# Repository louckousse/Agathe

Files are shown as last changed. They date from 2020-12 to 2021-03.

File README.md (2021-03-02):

# Agathe
Another Alice-clone

Following a 65% approach with close arrow-cluster and support for rotary encoders

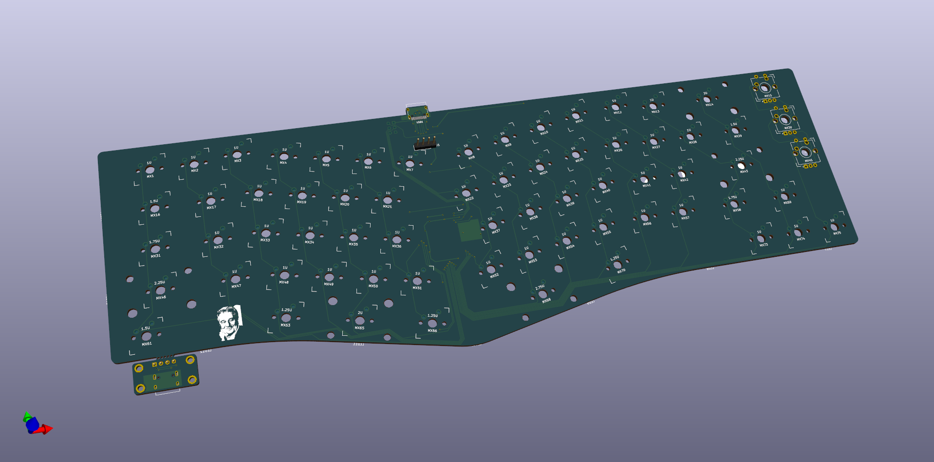
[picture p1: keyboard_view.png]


All the pcb files are created in Kicad, you can find everything in the root folder.

## Development

clone this repos with submodules
```
git clone --recurse-submodule https://github.com/louckousse/Agathe.git
```

## Building
When building this keyboard if you want to use the one rotary encoders you'll have to solder the jumper between the middle pad to the pad 1. If you want to use multiple, solder the other way around and check [this pr](https://github.com/qmk/qmk_firmware/pull/7209).
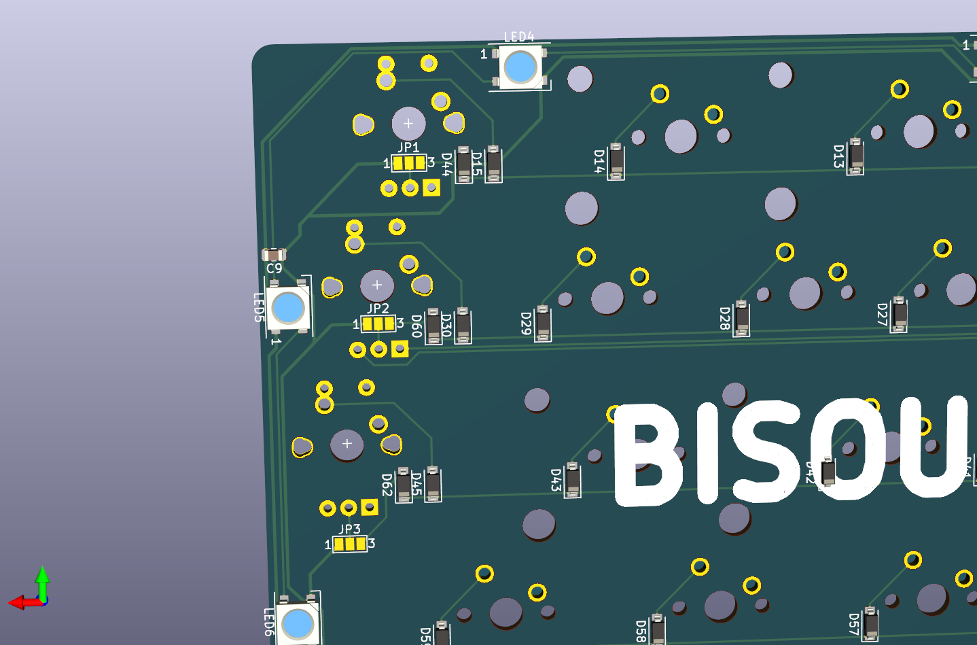
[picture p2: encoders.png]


## Keymap
You can find the keymap under my [QMK fork](https://github.com/louckousse/keymaps/tree/main/agathe).

# License
This work is licensed under a [Attribution-NonCommercial-ShareAlike 4.0 International (CC BY-NC-SA 4.0)](https://creativecommons.org/licenses/by-nc-sa/4.0/).

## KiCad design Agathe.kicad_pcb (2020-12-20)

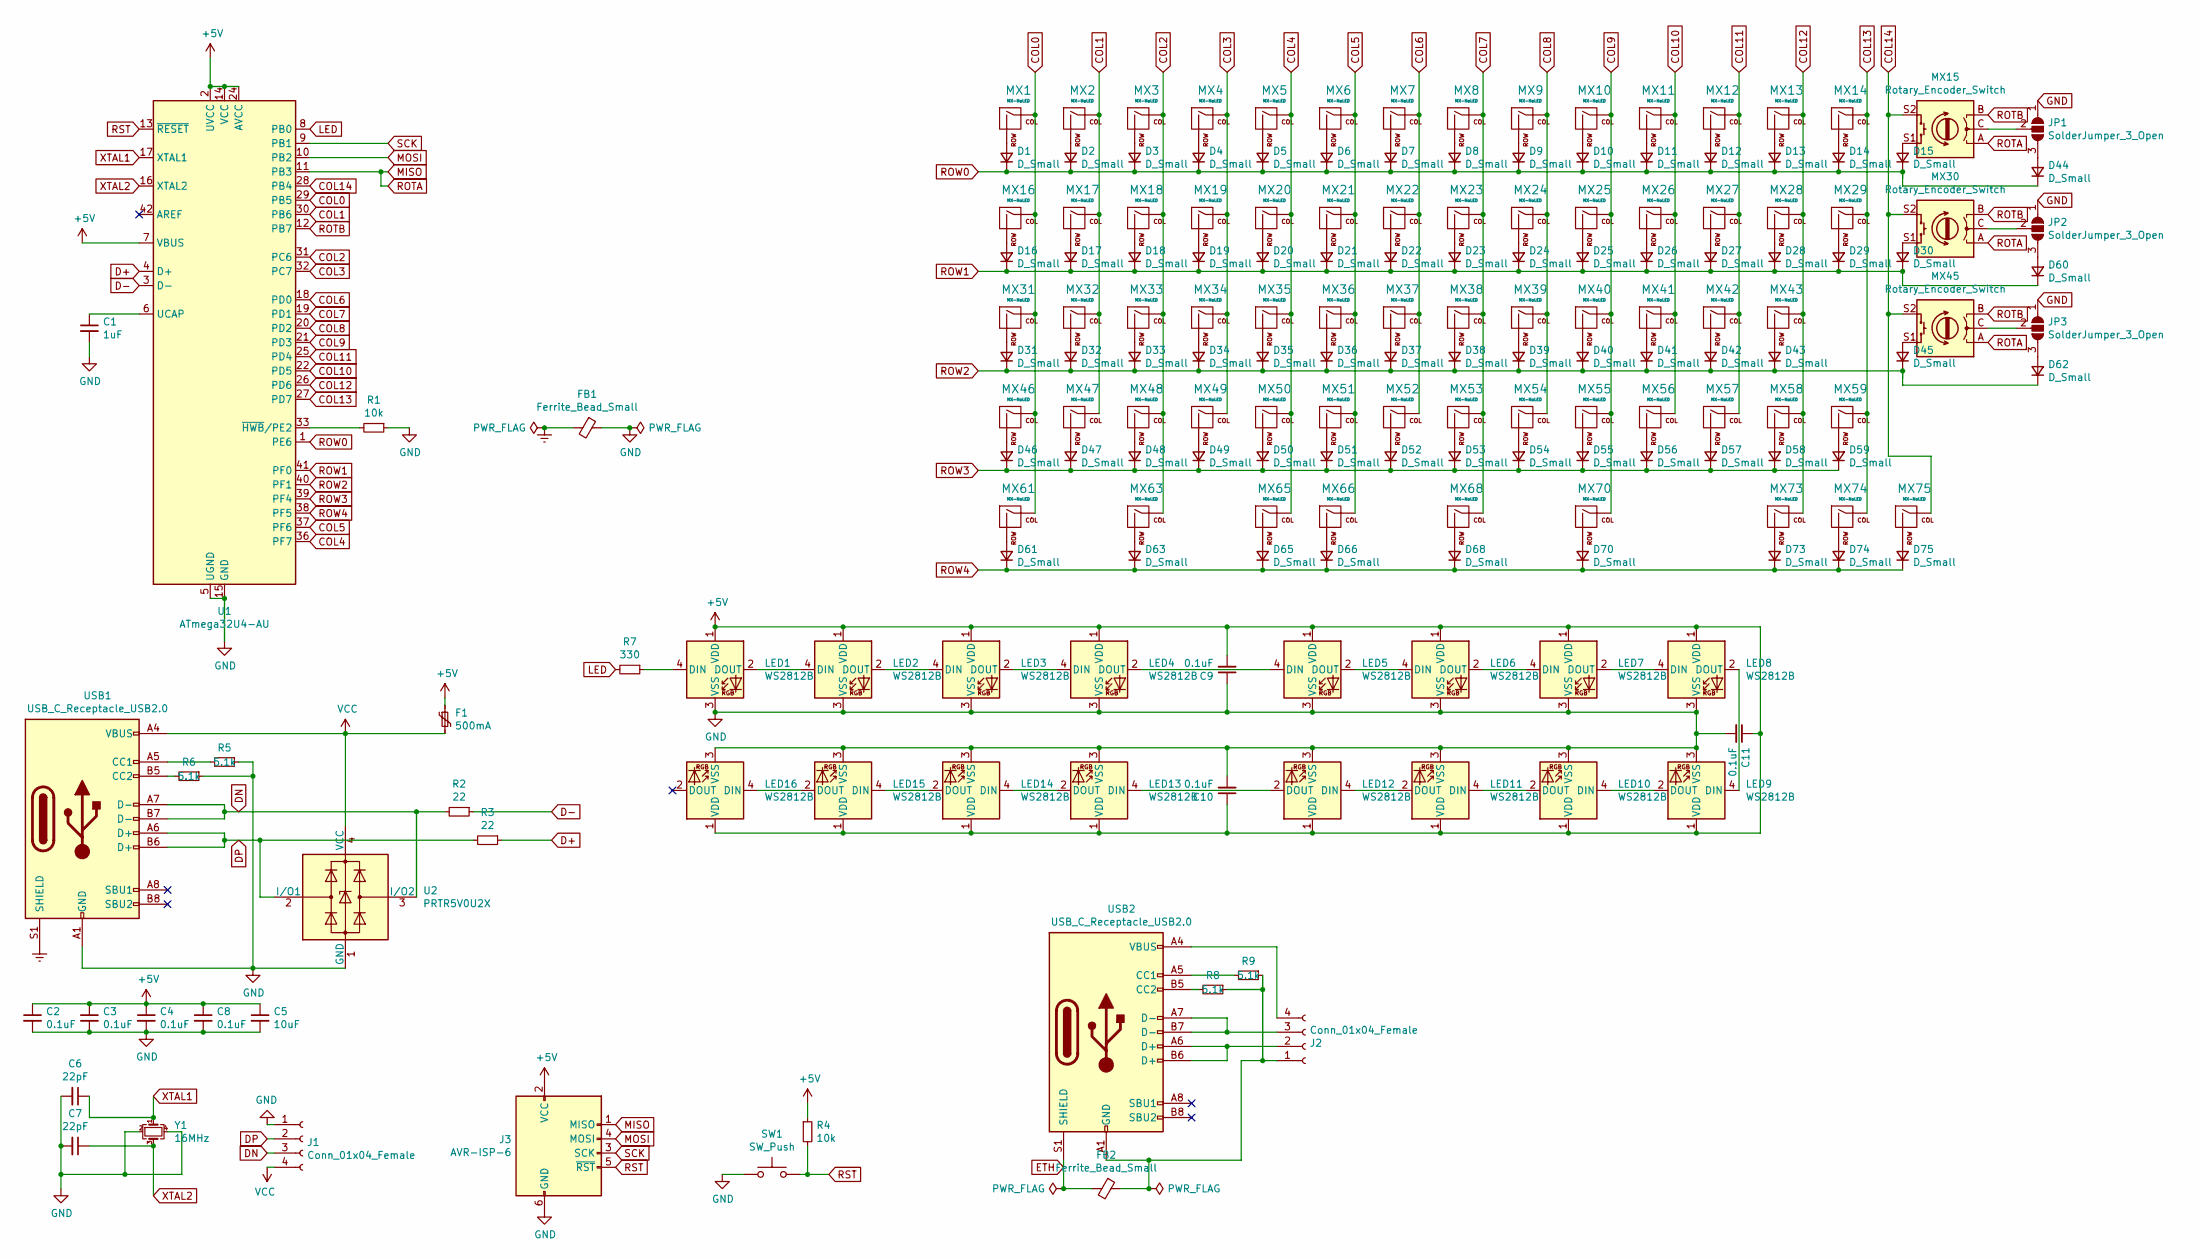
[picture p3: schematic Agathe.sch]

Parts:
C1: 1uF; C_0805_2012Metric
C2, C3, C4, C8, C9, C10, C11: 0.1uF; C_0805_2012Metric
C5: 10uF; C_0805_2012Metric
C6, C7: 22pF; C_0805_2012Metric
D1, D2, D3, D4, D5, D6, D7, D8, D9, D10, D11, D12, D13, D14, D15, D16, D17, D18, D19, D20, D21, D22, D23, D24, D25, D26, D27, D28, D29, D30, D31, D32, D33, D34, D35, D36, D37, D38, D39, D40, D41, D42, D43, D44, D45, D46, D47, D48, D49, D50, D51, D52, D53, D54, D55, D56, D57, D58, D59, D60, D61, D62, D63, D65, D66, D68, D70, D73, D74, D75: D_Small; D_SOD-123
F1: 500mA; Fuse_1206_3216Metric
FB1, FB2: Ferrite_Bead_Small; L_0805_2012Metric_Pad1.15x1.40mm_HandSolder
J1, J2: Conn_01x04_Female; PinHeader_1x04_P2.54mm_Vertical
J3: AVR-ISP-6; Reset_Pretty-Mask
JP1, JP2, JP3: SolderJumper_3_Open; SolderJumper-3_P1.3mm_Open_Pad1.0x1.5mm_NumberLabels
LED1, LED2, LED3, LED4, LED5, LED6, LED7, LED8, LED9, LED10, LED11, LED12, LED13, LED14, LED15, LED16: WS2812B; LED_WS2812B_PLCC4_5.0x5.0mm_P3.2mm
MX1, MX2, MX3, MX4, MX5, MX6, MX7, MX8, MX9, MX10, MX11, MX12, MX13, MX17, MX18, MX19, MX20, MX21, MX22, MX23, MX24, MX25, MX26, MX27, MX28, MX32, MX33, MX34, MX35, MX36, MX37, MX38, MX39, MX40, MX41, MX42, MX47, MX48, MX49, MX50, MX51, MX52, MX53, MX54, MX55, MX56, MX57, MX59, MX73, MX74, MX75: MX-NoLED; mx_1u
MX14: MX-NoLED; mx_2u
MX15, MX30, MX45: Rotary_Encoder_Switch; rotary_x_MX
MX16, MX29, MX61: MX-NoLED; mx_15u
MX31, MX58: MX-NoLED; mx_175u
MX43, MX46: MX-NoLED; mx_225u
MX63, MX66, MX70: MX-NoLED; mx_125u
MX65: MX-NoLED; mx_2ureverse
MX68: MX-NoLED; mx_275u_reverse
R1, R4: 10k; R_0805_2012Metric
R2, R3: 22; R_0805_2012Metric
R5, R6, R8, R9: 5.1k; R_0805_2012Metric
R7: 330; R_0805_2012Metric
SW1: SW_Push; SKQG-1155865
U1: ATmega32U4-AU; QFN-44-1EP_7x7mm_P0.5mm_EP5.2x5.2mm
U2: PRTR5V0U2X; SOT143B
USB1, USB2: USB_C_Receptacle_USB2.0; USB_C_Receptacle_HRO_TYPE-C-31-M-12
Y1: 16MHz; Crystal_SMD_3225-4Pin_3.2x2.5mm

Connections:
+5V: C2.1, C3.1, C4.1, C5.1, C8.1, C9.2, C10.1, C11.1, F1.1, J3.2 (VCC), LED1.1 (VDD), LED2.1 (VDD), LED3.1 (VDD), LED4.1 (VDD), LED5.1 (VDD), LED6.1 (VDD), LED7.1 (VDD), LED8.1 (VDD), LED9.1 (VDD), LED10.1 (VDD), LED11.1 (VDD), LED12.1 (VDD), LED13.1 (VDD), LED14.1 (VDD), LED15.1 (VDD), LED16.1 (VDD), R4.1, U1.2 (UVCC), U1.7 (VBUS), U1.14 (VCC), U1.24 (AVCC), U1.34 (VCC), U1.44 (AVCC)
COL0: MX1.1 (COL), MX16.1 (COL), MX31.1 (COL), MX46.1 (COL), MX61.1 (COL), U1.29 (PB5)
COL1: MX2.1 (COL), MX17.1 (COL), MX32.1 (COL), MX47.1 (COL), U1.30 (PB6)
COL2: MX3.1 (COL), MX18.1 (COL), MX33.1 (COL), MX48.1 (COL), MX63.1 (COL), U1.31 (PC6)
COL3: MX4.1 (COL), MX19.1 (COL), MX34.1 (COL), MX49.1 (COL), U1.32 (PC7)
COL4: MX5.1 (COL), MX20.1 (COL), MX35.1 (COL), MX50.1 (COL), MX65.1 (COL), U1.36 (PF7)
COL5: MX6.1 (COL), MX21.1 (COL), MX36.1 (COL), MX51.1 (COL), MX66.1 (COL), U1.37 (PF6)
COL6: MX7.1 (COL), MX22.1 (COL), MX37.1 (COL), MX52.1 (COL), U1.18 (PD0)
COL7: MX8.1 (COL), MX23.1 (COL), MX38.1 (COL), MX53.1 (COL), MX68.1 (COL), U1.19 (PD1)
COL8: MX9.1 (COL), MX24.1 (COL), MX39.1 (COL), MX54.1 (COL), U1.20 (PD2)
COL9: MX10.1 (COL), MX25.1 (COL), MX40.1 (COL), MX55.1 (COL), MX70.1 (COL), U1.21 (PD3)
COL10: MX11.1 (COL), MX26.1 (COL), MX41.1 (COL), MX56.1 (COL), U1.22 (PD5)
COL11: MX12.1 (COL), MX27.1 (COL), MX42.1 (COL), MX57.1 (COL), U1.25 (PD4)
COL12: MX13.1 (COL), MX28.1 (COL), MX43.1 (COL), MX58.1 (COL), MX73.1 (COL), U1.26 (PD6)
COL13: MX14.1 (COL), MX29.1 (COL), MX59.1 (COL), MX74.1 (COL), U1.27 (PD7)
COL14: MX15.S2, MX30.S2, MX45.S2, MX75.1 (COL), U1.28 (PB4)
D+: R3.1, U1.4 (D+)
D-: R2.1, U1.3 (D-)
DN: J1.3, R2.2, U2.3 (I/O2), USB1.A7 (D-), USB1.B7 (D-)
DP: J1.2, R3.2, U2.2 (I/O1), USB1.A6 (D+), USB1.B6 (D+)
ETH: FB2.2, USB2.S1 (SHIELD)
Earth: FB1.2, USB1.S1 (SHIELD)
GND: C1.2, C2.2, C3.2, C4.2, C5.2, C6.2, C7.2, C8.2, C9.1, C10.2, C11.2, FB1.1, J1.1, J3.6 (GND), JP1.1 (A), JP2.1 (A), JP3.1 (A), LED1.3 (VSS), LED2.3 (VSS), LED3.3 (VSS), LED4.3 (VSS), LED5.3 (VSS), LED6.3 (VSS), LED7.3 (VSS), LED8.3 (VSS), LED9.3 (VSS), LED10.3 (VSS), LED11.3 (VSS), LED12.3 (VSS), LED13.3 (VSS), LED14.3 (VSS), LED15.3 (VSS), LED16.3 (VSS), R1.1, R5.1, R6.1, SW1.1, U1.5 (UGND), U1.15 (GND), U1.23 (GND), U1.35 (GND), U1.43 (GND), U1.45, U2.1 (GND), USB1.A1 (GND), USB1.A12 (GND), USB1.B1 (GND), USB1.B12 (GND), Y1.2, Y1.4
LED: R7.2, U1.8 (PB0)
MISO: J3.1 (MISO), MX15.A, MX30.A, MX45.A, U1.11 (PB3)
MOSI: J3.4 (MOSI), U1.10 (PB2)
unnamed: C1.1, U1.6 (UCAP)
unnamed: D1.2 (A), MX1.2 (ROW)
unnamed: D2.2 (A), MX2.2 (ROW)
unnamed: D3.2 (A), MX3.2 (ROW)
unnamed: D4.2 (A), MX4.2 (ROW)
unnamed: D5.2 (A), MX5.2 (ROW)
unnamed: D6.2 (A), MX6.2 (ROW)
unnamed: D7.2 (A), MX7.2 (ROW)
unnamed: D8.2 (A), MX8.2 (ROW)
unnamed: D9.2 (A), MX9.2 (ROW)
unnamed: D10.2 (A), MX10.2 (ROW)
unnamed: D11.2 (A), MX11.2 (ROW)
unnamed: D12.2 (A), MX12.2 (ROW)
unnamed: D13.2 (A), MX13.2 (ROW)
unnamed: D14.2 (A), MX14.2 (ROW)
unnamed: D15.2 (A), MX15.S1
unnamed: D16.2 (A), MX16.2 (ROW)
unnamed: D17.2 (A), MX17.2 (ROW)
unnamed: D18.2 (A), MX18.2 (ROW)
unnamed: D19.2 (A), MX19.2 (ROW)
unnamed: D20.2 (A), MX20.2 (ROW)
unnamed: D21.2 (A), MX21.2 (ROW)
unnamed: D22.2 (A), MX22.2 (ROW)
unnamed: D23.2 (A), MX23.2 (ROW)
unnamed: D24.2 (A), MX24.2 (ROW)
unnamed: D25.2 (A), MX25.2 (ROW)
unnamed: D26.2 (A), MX26.2 (ROW)
unnamed: D27.2 (A), MX27.2 (ROW)
unnamed: D28.2 (A), MX28.2 (ROW)
unnamed: D29.2 (A), MX29.2 (ROW)
unnamed: D30.2 (A), MX30.S1
unnamed: D31.2 (A), MX31.2 (ROW)
unnamed: D32.2 (A), MX32.2 (ROW)
unnamed: D33.2 (A), MX33.2 (ROW)
unnamed: D34.2 (A), MX34.2 (ROW)
unnamed: D35.2 (A), MX35.2 (ROW)
unnamed: D36.2 (A), MX36.2 (ROW)
unnamed: D37.2 (A), MX37.2 (ROW)
unnamed: D38.2 (A), MX38.2 (ROW)
unnamed: D39.2 (A), MX39.2 (ROW)
unnamed: D40.2 (A), MX40.2 (ROW)
unnamed: D41.2 (A), MX41.2 (ROW)
unnamed: D42.2 (A), MX42.2 (ROW)
unnamed: D43.2 (A), MX43.2 (ROW)
unnamed: D44.2 (A), JP1.3 (B)
unnamed: D45.2 (A), MX45.S1
unnamed: D46.2 (A), MX46.2 (ROW)
unnamed: D47.2 (A), MX47.2 (ROW)
unnamed: D48.2 (A), MX48.2 (ROW)
unnamed: D49.2 (A), MX49.2 (ROW)
unnamed: D50.2 (A), MX50.2 (ROW)
unnamed: D51.2 (A), MX51.2 (ROW)
unnamed: D52.2 (A), MX52.2 (ROW)
unnamed: D53.2 (A), MX53.2 (ROW)
unnamed: D54.2 (A), MX54.2 (ROW)
unnamed: D55.2 (A), MX55.2 (ROW)
unnamed: D56.2 (A), MX56.2 (ROW)
unnamed: D57.2 (A), MX57.2 (ROW)
unnamed: D58.2 (A), MX58.2 (ROW)
unnamed: D59.2 (A), MX59.2 (ROW)
unnamed: D60.2 (A), JP2.3 (B)
unnamed: D61.2 (A), MX61.2 (ROW)
unnamed: D62.2 (A), JP3.3 (B)
unnamed: D63.2 (A), MX63.2 (ROW)
unnamed: D65.2 (A), MX65.2 (ROW)
unnamed: D66.2 (A), MX66.2 (ROW)
unnamed: D68.2 (A), MX68.2 (ROW)
unnamed: D70.2 (A), MX70.2 (ROW)
unnamed: D73.2 (A), MX73.2 (ROW)
unnamed: D74.2 (A), MX74.2 (ROW)
unnamed: D75.2 (A), MX75.2 (ROW)
unnamed: FB2.1, J2.1, R8.1, R9.1, USB2.A1 (GND), USB2.A12 (GND), USB2.B1 (GND), USB2.B12 (GND)
unnamed: J2.2, USB2.A6 (D+), USB2.B6 (D+)
unnamed: J2.3, USB2.A7 (D-), USB2.B7 (D-)
unnamed: J2.4, USB2.A4 (VBUS), USB2.A9 (VBUS), USB2.B4 (VBUS), USB2.B9 (VBUS)
unnamed: JP1.2 (C), MX15.C
unnamed: JP2.2 (C), MX30.C
unnamed: JP3.2 (C), MX45.C
unnamed: LED1.2 (DOUT), LED2.4 (DIN)
unnamed: LED1.4 (DIN), R7.1
unnamed: LED2.2 (DOUT), LED3.4 (DIN)
unnamed: LED3.2 (DOUT), LED4.4 (DIN)
unnamed: LED4.2 (DOUT), LED5.4 (DIN)
unnamed: LED5.2 (DOUT), LED6.4 (DIN)
unnamed: LED6.2 (DOUT), LED7.4 (DIN)
unnamed: LED7.2 (DOUT), LED8.4 (DIN)
unnamed: LED8.2 (DOUT), LED9.4 (DIN)
unnamed: LED10.2 (DOUT), LED11.4 (DIN)
unnamed: LED9.2 (DOUT), LED10.4 (DIN)
unnamed: LED11.2 (DOUT), LED12.4 (DIN)
unnamed: LED12.2 (DOUT), LED13.4 (DIN)
unnamed: LED13.2 (DOUT), LED14.4 (DIN)
unnamed: LED14.2 (DOUT), LED15.4 (DIN)
unnamed: LED15.2 (DOUT), LED16.4 (DIN)
unnamed: R1.2, U1.33 (~HWB~/PE2)
unnamed: R5.2, USB1.A5 (CC1)
unnamed: R6.2, USB1.B5 (CC2)
unnamed: R8.2, USB2.B5 (CC2)
unnamed: R9.2, USB2.A5 (CC1)
ROTB: MX15.B, MX30.B, MX45.B, U1.12 (PB7)
ROW0: D1.1 (K), D2.1 (K), D3.1 (K), D4.1 (K), D5.1 (K), D6.1 (K), D7.1 (K), D8.1 (K), D9.1 (K), D10.1 (K), D11.1 (K), D12.1 (K), D13.1 (K), D14.1 (K), D15.1 (K), D44.1 (K), U1.1 (PE6)
ROW1: D16.1 (K), D17.1 (K), D18.1 (K), D19.1 (K), D20.1 (K), D21.1 (K), D22.1 (K), D23.1 (K), D24.1 (K), D25.1 (K), D26.1 (K), D27.1 (K), D28.1 (K), D29.1 (K), D30.1 (K), D60.1 (K), U1.41 (PF0)
ROW2: D31.1 (K), D32.1 (K), D33.1 (K), D34.1 (K), D35.1 (K), D36.1 (K), D37.1 (K), D38.1 (K), D39.1 (K), D40.1 (K), D41.1 (K), D42.1 (K), D43.1 (K), D45.1 (K), D62.1 (K), U1.40 (PF1)
ROW3: D46.1 (K), D47.1 (K), D48.1 (K), D49.1 (K), D50.1 (K), D51.1 (K), D52.1 (K), D53.1 (K), D54.1 (K), D55.1 (K), D56.1 (K), D57.1 (K), D58.1 (K), D59.1 (K), U1.39 (PF4)
ROW4: D61.1 (K), D63.1 (K), D65.1 (K), D66.1 (K), D68.1 (K), D70.1 (K), D73.1 (K), D74.1 (K), D75.1 (K), U1.38 (PF5)
RST: J3.5 (~RST), R4.2, SW1.2, U1.13 (~RESET)
SCK: J3.3 (SCK), U1.9 (PB1)
VCC: F1.2, J1.4, U2.4 (VCC), USB1.A4 (VBUS), USB1.A9 (VBUS), USB1.B4 (VBUS), USB1.B9 (VBUS)
XTAL1: C6.1, U1.17 (XTAL1), Y1.1
XTAL2: C7.1, U1.16 (XTAL2), Y1.3

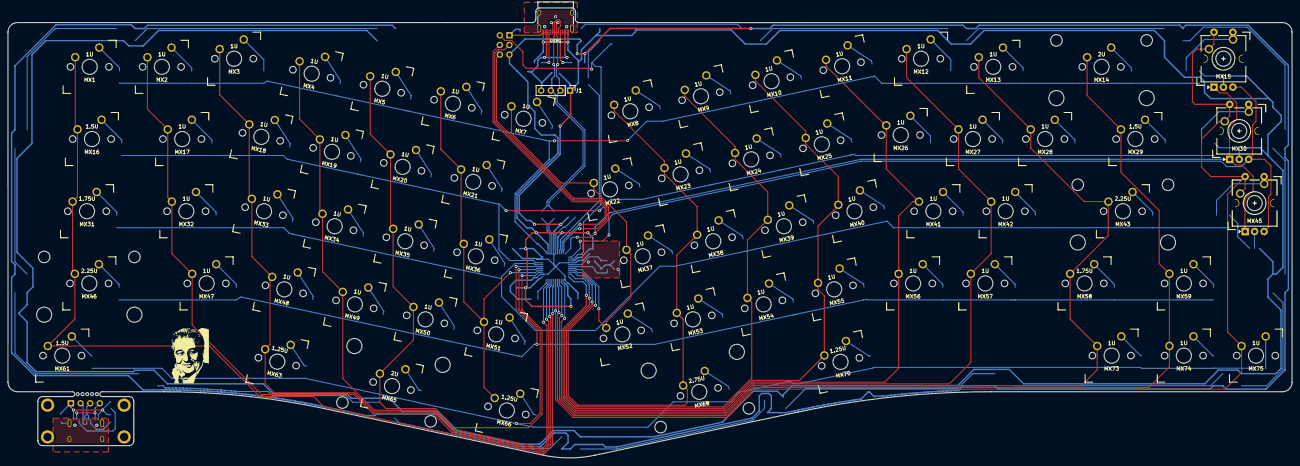
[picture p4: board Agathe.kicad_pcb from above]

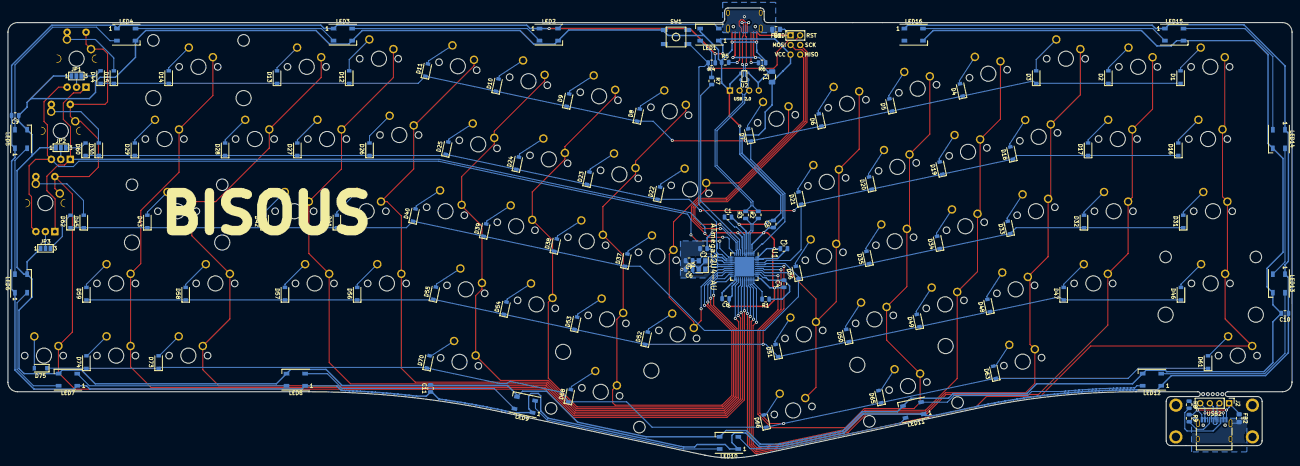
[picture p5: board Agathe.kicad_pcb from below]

Board: 2 copper layers, 338.8 x 118.7 mm, 188 parts (119 on the bottom side), 136 nets.

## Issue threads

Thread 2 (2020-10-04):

R_Small not defined ?

coliss86, 2020-10-04:
Where is `R_small` defined ?

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

coliss86, 2020-10-04:
Same question for  D_small and
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

louckousse, 2020-10-05:
It's normal for D_Small and Crystal.
It's an error for the R_Small tho'.

I'll look into it. Thank you.

coliss86, 2020-10-05:
**Where** is it defined ? ;)

what error did you find for R_Small ?

louckousse, 2020-10-07:
So, after checking it, I've forgotten the value for the crystal and the resistance according to this [tutorial](https://wiki.ai03.com/books/pcb-design/page/pcb-guide-part-3---creating-the-mcu-schematic). For the diodes, you don't need to change the value and you can leave it at d_small.

Thank you for spotting that.

Closed 2020-10-07.

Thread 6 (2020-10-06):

Lib not found

coliss86, 2020-10-06:
I have this error when opening footprint

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

louckousse, 2020-10-07:
I have this error too, I don't know why. I'll look into it one day.

louckousse, 2020-10-10:
I've merged your PR about the libs, does it correct this issue ?

coliss86, 2020-10-10:
Hum no :'(
I see that there is a ref to `fancy-kicad-stuff/cc.pretty` in `fp-lib-table`.

Do you need it ? It can be removed otherwisef

louckousse, 2020-10-10:
It's Christian Clavier ! I'll add it legit

coliss86, 2020-10-10:
I just update to latest master, another error :
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

Hard to fix :'(

coliss86, 2020-10-10:
Never mind, I didn't update submodules...

coliss86, 2020-10-10:
But : When I try to open `Agathe-cache.lib`, I still get a error.
I fixed it with #12

Closed 2024-06-16.

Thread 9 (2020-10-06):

VSS and VDD inverted on underglow LED

coliss86, 2020-10-06:
VSS must be connected to the Ground

VDD must be connected to 5V

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

Tips : the symbol of the LED is an arrow, the current flow through it.
```
VCC --|>|-- GND
```

Closed 2020-10-10.

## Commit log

2020-04-26 Create the initial schema
    [Agathe.sch]
2020-04-26 Current layout before deleted keys
    [Agathe.kicad_pcb, Agathe.sch]
2020-04-26 day 2 of work
    MCU and USB routed
    All switch routed between them
    Todo: connect row and column to MCU
    [Agathe.kicad_pcb, Agathe.sch]
2020-04-27 Route everything
    [Agathe.kicad_pcb, Agathe.sch]
2020-04-28 change the enter footprint
    [Agathe.kicad_pcb, Agathe.sch]
2020-05-01 Add a proper usb-c
    [Agathe.kicad_pcb]
2020-05-01 Add .dxf files
    [bottom.dxf, mid.dxf, pcb_border.dxf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]
2020-05-02 Add rotary encoder support
    [Agathe.kicad_pcb, Agathe.sch]
2020-05-02 Add underglow
    [Agathe.kicad_pcb, Agathe.sch]
2020-05-09 Update footprints for switch
    [Agathe.kicad_pcb, Agathe.sch]
2020-10-07 add 2 breakout header for VCC and GND (#8)
    * Add submodule explanation
    * add render view
    * Rerouting around USB-C connector
    * WIP
    * end
    * end
    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
    [Agathe.kicad_pcb, Agathe.sch]
2020-10-07 correct some routes
    [Agathe.kicad_pcb]
2020-10-07 add value for rst resistor and crystal (#2)
    [Agathe.sch]
2020-10-08 Realign J3 and J2. Reroute D- around J4
    [Agathe.kicad_pcb]
2020-10-09 Move J2 to top
    [Agathe.kicad_pcb, Agathe.sch]
2020-10-10 Upgrade Keebio-Parts.pretty, add louckousse-kicad submodules (#10)
    * :arrow_up: Upgrade Keebio-Parts.pretty submodule to latest master
    * add louckousse-kicad
2020-10-10 move breakout to the top
    [Agathe.kicad_pcb]
2020-10-10 reverse vcc and gnd on leds (#9)
    [Agathe.kicad_pcb, Agathe.sch]
2020-10-18 add a capacitor
    [Agathe.kicad_pcb, Agathe.sch]
2020-10-24 update shematics
    add spi interface
    add 6 leds
    change the esp
    [Agathe.sch]
2020-10-25 j'ai putain de tout refait putain
    [Agathe.kicad_pcb, Agathe.sch]
2020-10-27 add some stuff after a review from @plut0nium
    Some new feature from the @masterzen blog article
    http://www.masterzen.fr/2020/10/20/designing-a-keyboard-part3/
    [Agathe.kicad_pcb, Agathe.sch]
2020-10-28 add a breakable usb port and matrix encoder
    [Agathe.kicad_pcb, Agathe.sch]
2020-10-31 add matrice rotary possibilities
    [Agathe.kicad_pcb, Agathe.sch]
2020-11-14 move the daughterboard at the bottom and change the mcu
    [Agathe.kicad_pcb, Agathe.sch]
2020-12-20 top mount usb-port
    [Agathe.kicad_pcb]
